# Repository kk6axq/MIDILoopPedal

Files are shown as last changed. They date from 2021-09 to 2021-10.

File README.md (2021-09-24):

# MIDI Loop Pedal
MIDILoopPedal is a Musical Instrument Digital Interface (MIDI) based loop pedal for use with an electric piano. It enables the user to record, dub, and playback multiple tracks in realtime.

This project is being conducted as an Honors Enrichment Contract for EGR201, Use-Inspired Design Project I, at Arizona State University on the Polytechnic Campus through Barrett, the Honors College, at Arizona State University, and under the guidance of Dr. Adam Carberry.
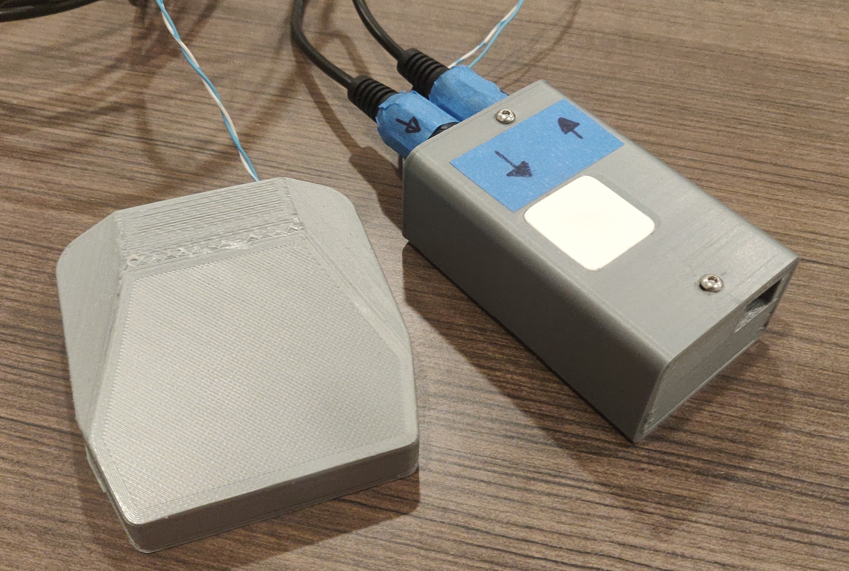
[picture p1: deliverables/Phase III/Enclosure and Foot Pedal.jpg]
Project Photo


## Project Status
This project is organized into four main phases and two stretch phases. Minimum success will be demonstrated by completion of phase IV.<br>
**Phase I: Complete**
* ~~Create block diagram of major components~~
* ~~Select electrical components and build schematic~~
* ~~Build CAD model concept~~

**Phase II: Complete**
* ~~Build breadboard layout of electrical system~~
* ~~Test functionality of electrical system to receive and send key events~~
* ~~Build Solidworks Assembly of body~~

**Phase III: Complete**
* ~~Build proto-board or PCB layout for electrical system~~
* ~~Assemble electrical and mechanical system~~

**Phase IV: In Progress**
* Develop software to record and play back key events
* Test complete system

**Stretch Goal I:**
* Add USB MIDI interface mode

**Stretch Goal II:**
* Add multi-track recording or playback

## Project Structure
This repository will contain all files from the project as it progresses. The current structure is:
* **hardware**: Hardware design files for the CAD and EDA parts of the project. CAD parts are designed in Solidworks, and the electrical schematics are designed in KiCAD.
* **software**: Source code for the testing, validation, and operation aspects of the project. The Teensy 4.1 microcontroller is programmed through the Arduino environment, and all source code is in C/C++.
* **deliverables**: Deliverables for the different phases of the project. These are copies of the different files at the time of phase completion, but they serve as a moment-in-time survey of the project and help illustrate the design evolution over time.

## Contact
To get in touch, send me an email: kk6axq@gmail.com

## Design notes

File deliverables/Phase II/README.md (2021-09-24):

# Phase II
Phase II deliverables centered around the testing of the electrical system and initial enclosure.

## Breadboard layout
The breadboard layout helped validate the schematic and component selection. The power LED was removed as the WS2812B indicator was found to be sufficient. The breadboard also allowed testing the initial software and ensuring communication between the microcontroller and the piano worked.

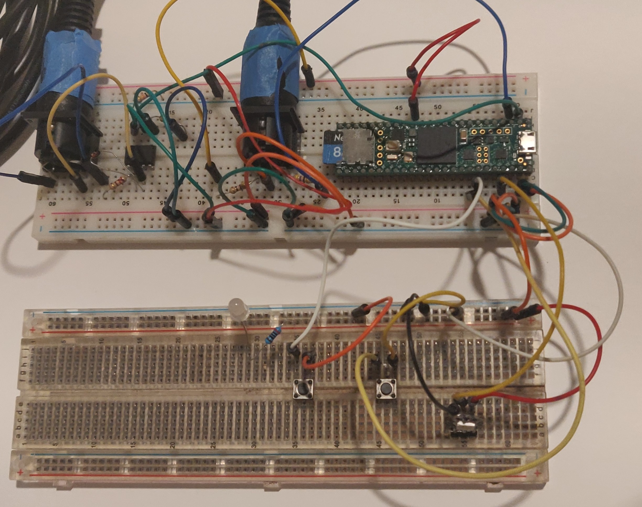
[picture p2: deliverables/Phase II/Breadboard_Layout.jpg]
PCB Front Photo


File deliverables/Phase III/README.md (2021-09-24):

# Phase III
Phase III transferred the project from a breadboard to proto board, enabling a more permanent solution. Aspects of this were completed in conjunction with Phase II, as the hardware design files for Phase II required the dimensions of the PCB from Phase III.

# Proto-board layout
The transfer from breadboard to proto-board went well. There was one minor issue with a pullup resistor that was in the wrong location (see dcd258a), but the rest of the assembly process went smoothly. Two PCBs had to be joined to create enough space for the parts, which is somewhat suboptimal, but so far it has held up well.

U2-Pin-Header was also added to the Bill of Materials as I didn't add the female pin headers that seated the microcontroller at an earlier stage.

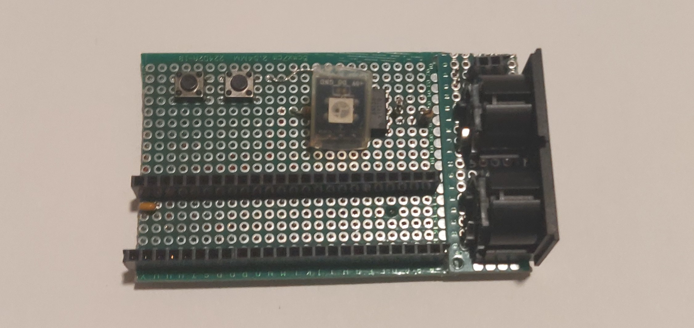
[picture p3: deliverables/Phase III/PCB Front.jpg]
PCB Front Photo

<br>
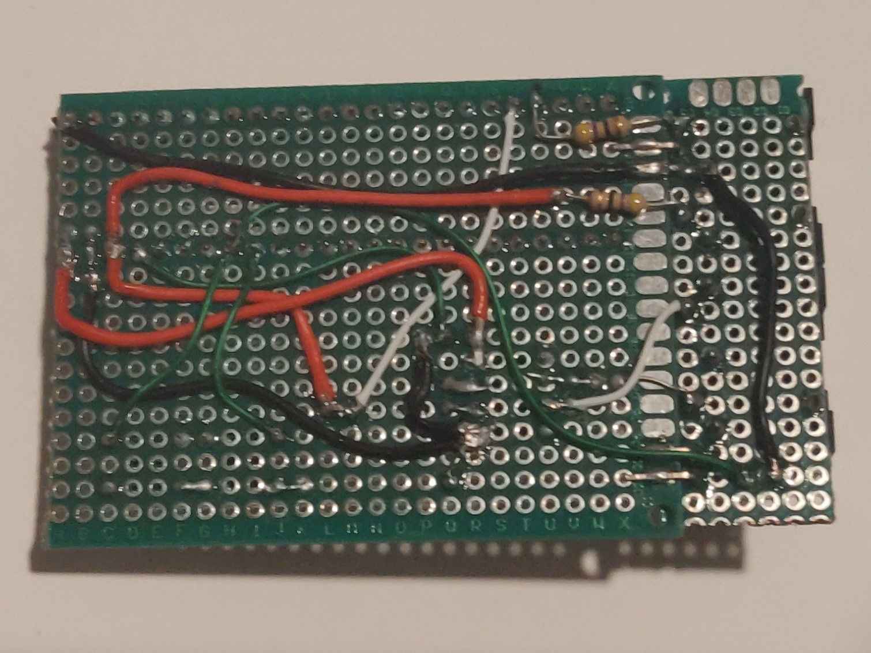
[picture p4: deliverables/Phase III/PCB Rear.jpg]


# Foot pedal
Pianists are already familiar with using foot pedals for controlling the sustain on a piano or keyboard, so I decided to use a footpedal as the control for the loop pedal. After some research, I found an open source design from Adafruit for a fully 3D printable foot pedal that interfaced with a common tactile switch. The design, available here: https://www.thingiverse.com/thing:2829107, prints in three pieces and can be easily glued or screwed together. I chose to screw the switch into the bracket and glue the bracket into the base.

# Bill of Materials
The Bill of Materials and schematic got an update as the foot pedal got added and some miscellaneous parts and connectors were included. The only two items not listed on the BOM, as far as I know, are the proto-board itself and the wire that runs between the foot pedal and the base unit. I'm currently using salvaged wire that I got at no cost, so unless I move this to commercial production, I won't add a source for the 2 conductor cable.

# Assembly
The order of assembly is fairly straightforward:
* Assemble the PCB
* Glue the connector bracket to the connectors. For this I used hot glue for ease of removability if ever needed.
* Insert the captive nuts into the slots on the connector bracket and USB end cap.
* Fit and glue the window into the slot in the enclosure tube.
* Slide the PCB into the enclosure tube, with the connectors at the slightly closed end.
* Install the USB end cap to hold the PCB in place.
* Install the 2 M3x12 screws to hold the connector bracket and USB end cap in place.
Board Photo

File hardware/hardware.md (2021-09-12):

The KiCAD project depends on symbols and footprints from the Teensy KiCAD library, included as a submodule in the `libraries` folder: https://github.com/XenGi/teensy_library

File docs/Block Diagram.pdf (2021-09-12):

Microcontroller
(Teensy 4.1)

MIDI
Interface
Circuitry
Computer | Instrument

LED
Indicator

Buttons

Storage Medium
Built-In

Red: Power (3.3/5V)
Blue: UART
Green: GPIO
Orange: MIDI

Internal to device

MIDI Loop Pedal Component Block Diagram

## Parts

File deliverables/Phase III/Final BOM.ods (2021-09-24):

MIDI Loop Pedal |  |  |  |  | Revision | 2
Bill of Materials
Electrical parts
Designator | Value | Qty | Unit Price | Qty 10 Price | Digikey Part # | Note |  | Single unit price | Batch price
SW1, SW2 | Tactile SPST | 2 | $0.10 | $0.091 | 679-2428-ND
SW3 | Micro-switch | 1 | $1.95 | $1.760 | https://www.adafruit.com/product/817 | Standard arcade button
U1 | 6N138 | 1 | $0.80 | $0.522 | 160-1795-ND |  |  | $0.80 | $0.522
U2 | Teensy 4.1 | 1 | $31.88 | $31.880 | 1568-DEV-16996-ND | Cheaper without headers |  | $31.88 | $31.880
C1 | 0.1u | 1 | $0.23 | $0.157 | 399-4151-ND |  |  | $0.23 | $0.157
R1,R3 | 470 | 2 | $0.10 | $0.036 | CF14JT470RCT-ND |  |  | $0.20 | $0.072
R2 | 10k | 1 | $0.10 | $0.036 | CF14JT10K0CT-ND |  |  | $0.10 | $0.036
R4,R5 | 47 | 2 | $0.10 | $0.036 | CF14JT47R0CT-ND |  |  | $0.20 | $0.072
D1 | 1N4148 | 1 | $0.10 | $0.071 | 1N4148-T26ACT-ND |  |  | $0.10 | $0.071
D3 | WS2812B | 1 | $0.10 | $0.103 | N/A | One module from a generic WS2812B strip. |  | $0.10 | $0.103
J1,J2 | DIN-5 | 2 | $2.15 | $1.870 | CP-2350-ND |  |  | $4.30 | $3.740
J3 | 2 pin female | 1 | $0.10 | $0.076 | 2057-PH1RA-02-UA-ND |  |  | $0.10 | $0.076
J4 | 2 pin male | 1 | $0.18 | $0.149 | 2057-RS1-02-G-ND |  |  | $0.18 | $0.149
U2-Pin-Header | 24 pin | 2 | $1.37 | $1.193 | S7022-ND | Female headers for making U2 removable |  | $2.74 | $2.386
 |  |  |  |  |  |  | Single unit part cost | $40.93
 |  |  |  |  |  |  | Batch of 10 units part cost |  | $39.26
Mechanical parts |  |  |  |  | Note:
Name | Qty | Unit Price | Note |  | All 3D printed part costs estimated by slicer weight with supports at $25/kg
M3x12 bolt | 4 | $0.02
M3 nut | 4 | $0.02
Connector Bracket | 1 | $0.05
USB End Cap | 1 | $0.15
Enclosure Tube | 1 | $1.10
Window | 1 | $0.03 | White or clear filament
Pedal Top | 1 | $0.58
Pedal Bracket | 1 | $0.08
Pedal Base | 1 | $0.48
 | Part cost: | $2.49
Total cost: | Electrical | Mechanical | Net Cost | Unit Cost
1 unit | $40.93 | $2.49 | $43.42 | $43.42
10 units | $392.64 | $24.90 | $417.54 | $41.75

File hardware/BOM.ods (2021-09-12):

MIDI Loop Pedal |  |  |  |  | Revision | 2
Bill of Materials
Designator | Value | Qty | Unit Price | Qty 10 Price | Digikey Part # | Note |  | Single unit price | Batch price
U1 | 6N138 | 1 | $0.80 | $0.522 | 160-1795-ND |  |  | $0.80 | $0.522
U2 | Teensy 4.1 | 1 | $31.88 | $31.880 | 1568-DEV-16996-ND | Cheaper without headers |  | $31.88 | $31.880
C1 | 0.1u | 1 | $0.23 | $0.157 | 399-4151-ND |  |  | $0.23 | $0.157
R1,R3 | 470 | 2 | $0.10 | $0.036 | CF14JT470RCT-ND |  |  | $0.20 | $0.072
R2 | 10k | 1 | $0.10 | $0.036 | CF14JT10K0CT-ND |  |  | $0.10 | $0.036
R4,R5 | 47 | 2 | $0.10 | $0.036 | CF14JT47R0CT-ND |  |  | $0.20 | $0.072
R6 | 220 | 1 | $0.10 | $0.036 | CF14JT220RCT-ND |  |  | $0.10 | $0.036
D1 | 1N4148 | 1 | $0.10 | $0.071 | 1N4148-T26ACT-ND |  |  | $0.10 | $0.071
D2 | Red | 1 | $0.15 | $0.140 | C503B-RCN-CW0Z0AA1-ND |  |  | $0.15 | $0.140
D3 | WS2812B | 1 | $0.10 | $0.103 | N/A | One module from a generic WS2812B strip. |  | $0.10 | $0.103
J1,J2 | DIN-5 | 2 | $2.15 | $1.870 | CP-2350-ND |  |  | $4.30 | $3.740
J3 | 2 pin | 1 | $0.10 | $0.076 | 2057-PH1RA-02-UA-ND |  |  | $0.10 | $0.076
 |  |  |  |  |  |  | Single unit part cost | $38.26
 |  |  |  |  |  |  | Batch of 10 units part cost |  | $36.90

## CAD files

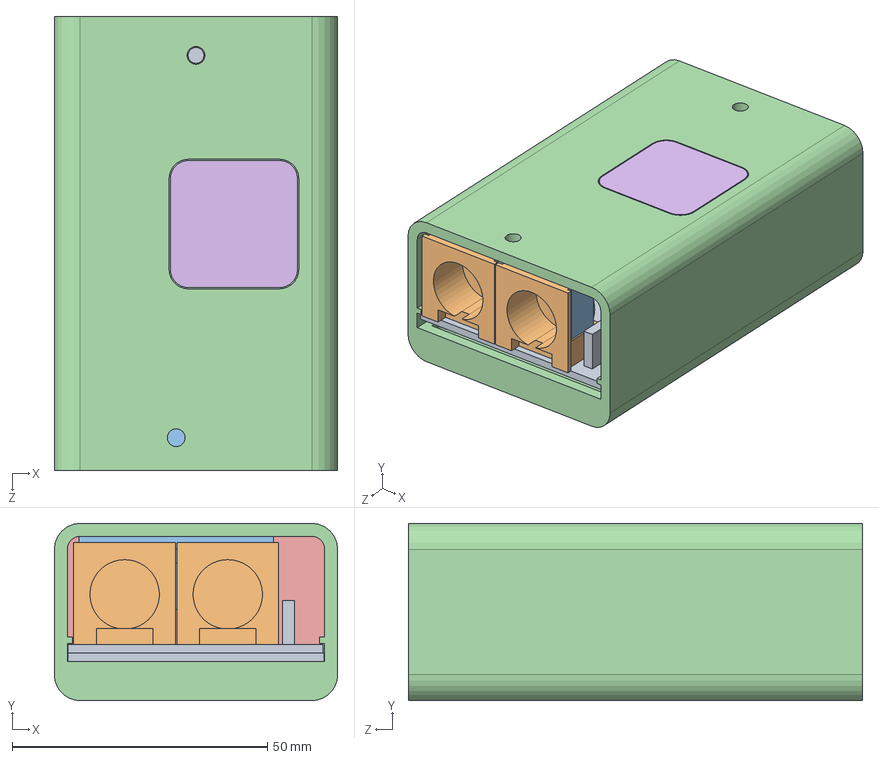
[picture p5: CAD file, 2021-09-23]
deliverables/Phase II/Enclosure Solidworks Files/V1 Assembly.SLDASM
55.5 x 34.7 x 88.9 mm
Proto-board
MIDI-connector x 2
Connector-Bracket
Enclosure-Tube
USB-End-Cap-v1
Window

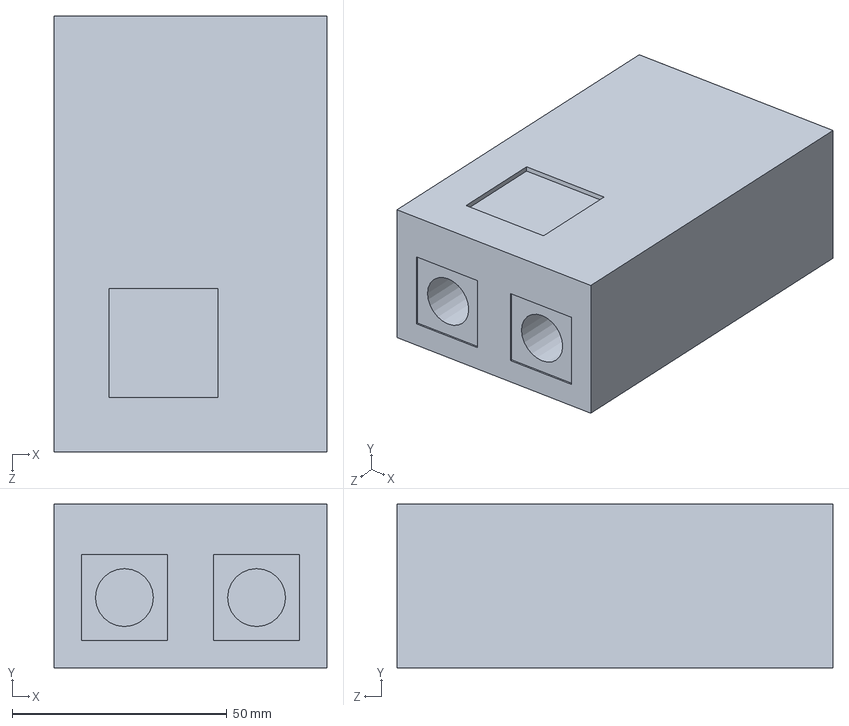
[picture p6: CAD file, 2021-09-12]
deliverables/Phase I/Device Mockup.SLDPRT
63.5 x 38.1 x 101.6 mm

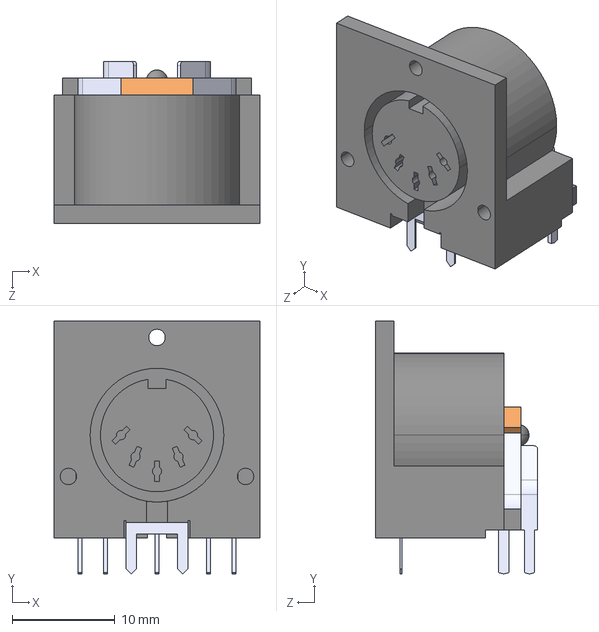
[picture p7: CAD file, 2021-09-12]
hardware/CAD/external_parts/MIDI_Connector.STEP
20.0 x 24.6 x 15.8 mm

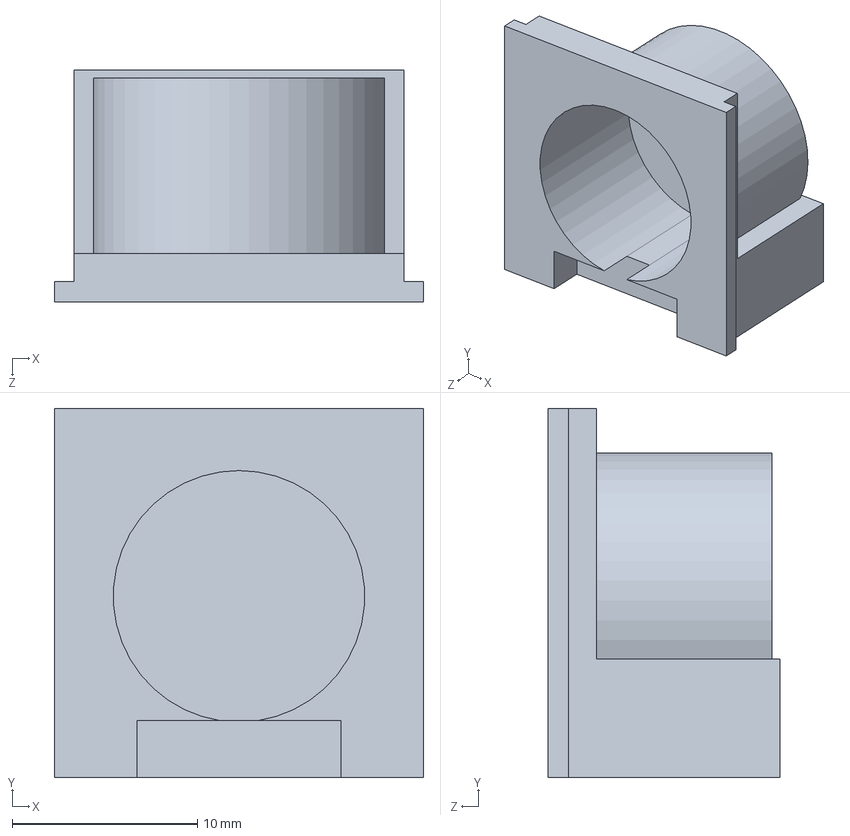
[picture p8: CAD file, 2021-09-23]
deliverables/Phase II/Enclosure Solidworks Files/MIDI-connector.SLDPRT
19.9 x 19.9 x 12.5 mm

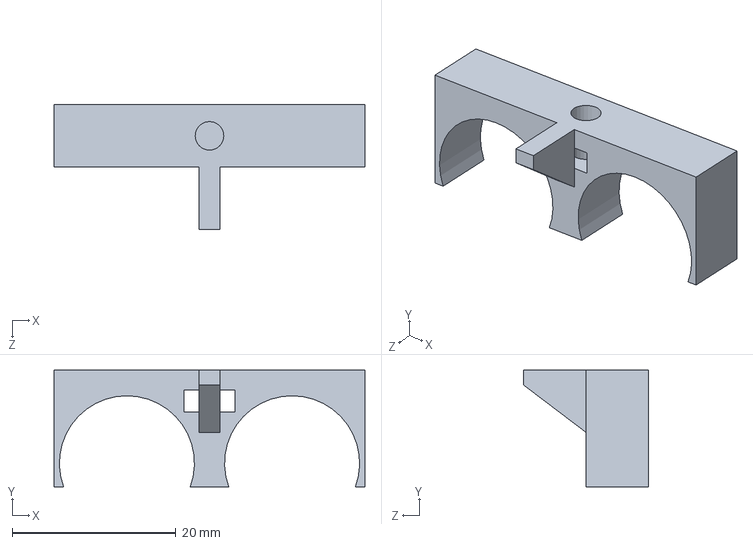
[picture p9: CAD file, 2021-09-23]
deliverables/Phase II/Enclosure Solidworks Files/Connector-Bracket.SLDPRT
38.0 x 14.3 x 15.2 mm

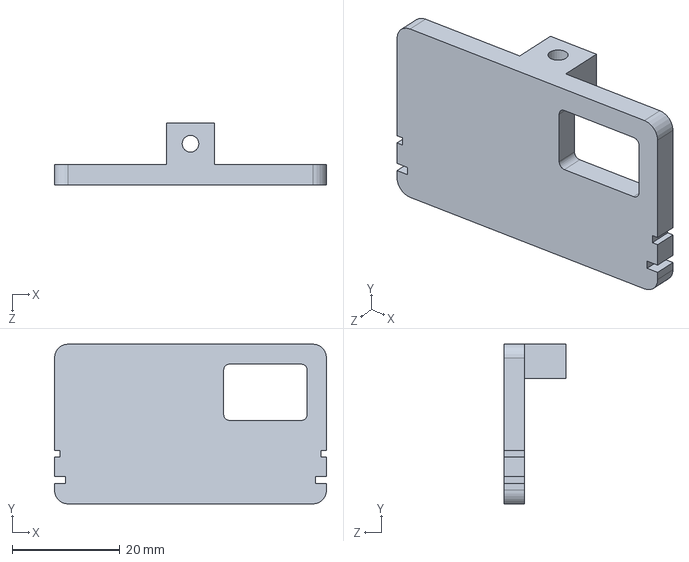
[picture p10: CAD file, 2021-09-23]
deliverables/Phase II/Enclosure Solidworks Files/USB-End-Cap-v1.SLDPRT
50.4 x 29.6 x 11.4 mm

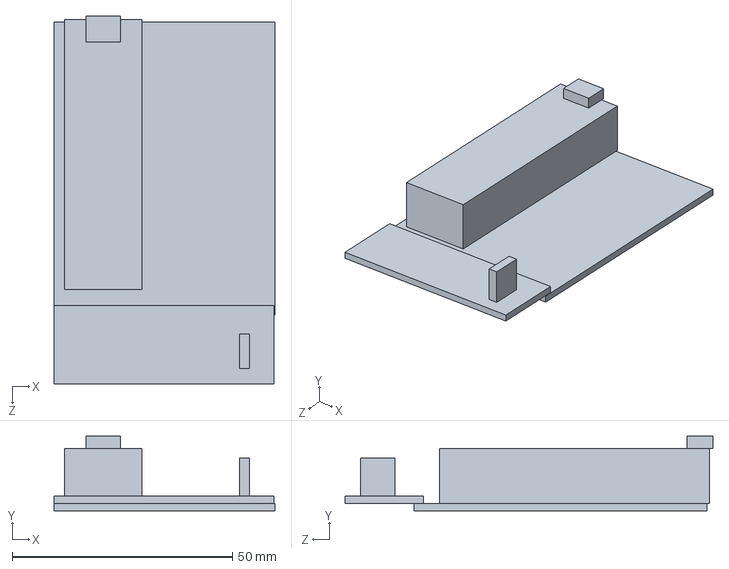
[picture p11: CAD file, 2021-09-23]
deliverables/Phase II/Enclosure Solidworks Files/Proto-board.SLDPRT
50.2 x 17.0 x 83.5 mm

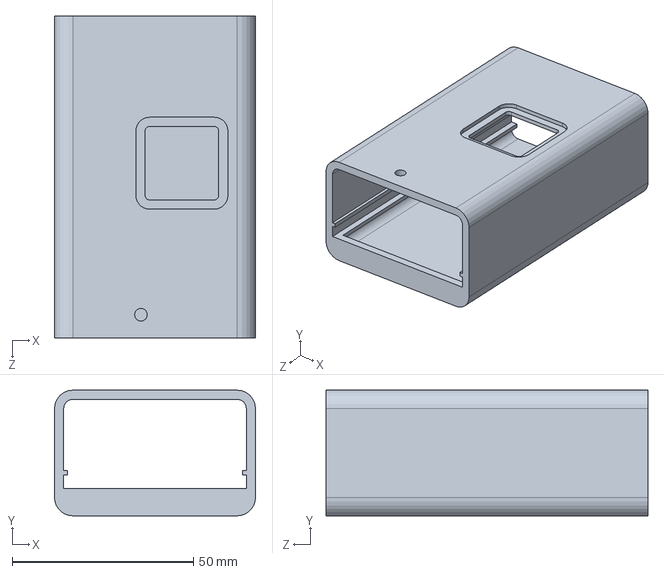
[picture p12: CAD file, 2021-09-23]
deliverables/Phase II/Enclosure Solidworks Files/Enclosure-Tube.SLDPRT
55.5 x 34.7 x 88.9 mm

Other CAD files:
deliverables/Phase II/Enclosure Solidworks Files/Window.SLDPRT
deliverables/Phase II/Enclosure STLs/Connector-Bracket.STL
deliverables/Phase II/Enclosure STLs/Enclosure-Tube.STL
deliverables/Phase II/Enclosure STLs/USB-End-Cap-v1.STL
deliverables/Phase II/Enclosure STLs/Window.STL

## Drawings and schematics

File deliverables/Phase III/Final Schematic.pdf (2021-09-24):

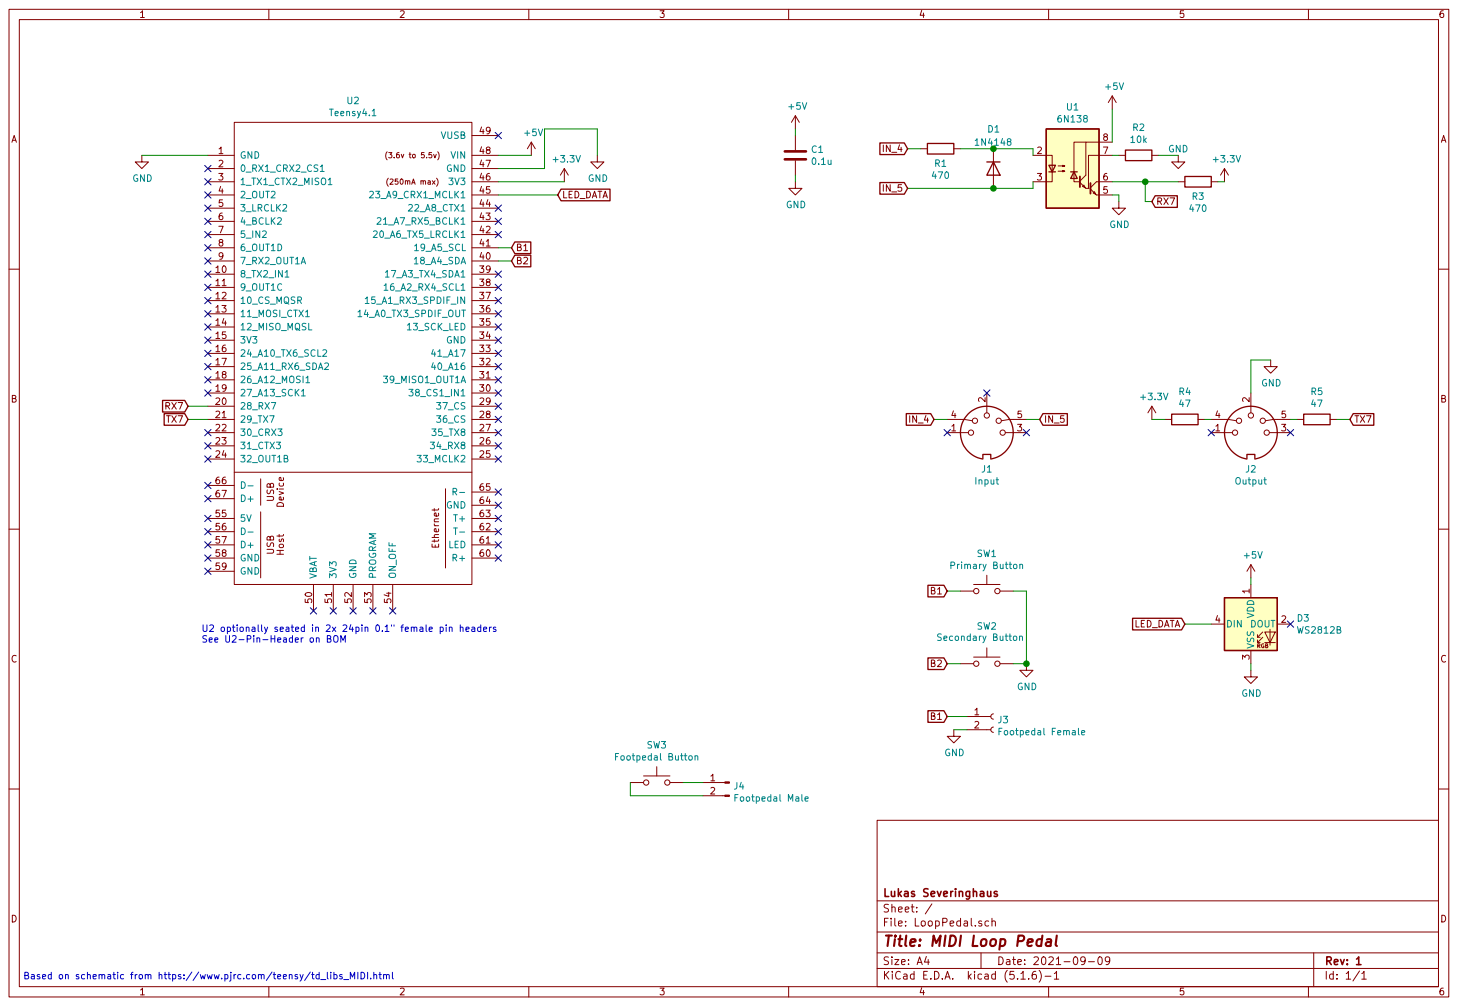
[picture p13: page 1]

LED_DATA RX7 Based on schematic from https://www.pjrc.com/teensy/td_libs_MIDI.html

U2 optionally seated in 2x 24pin 0.1" female pin headers See U2-Pin-Header on BOM

File: LoopPedal.sch Sheet: / Lukas Severinghaus

Id: 1/1 Title: MIDI Loop Pedal

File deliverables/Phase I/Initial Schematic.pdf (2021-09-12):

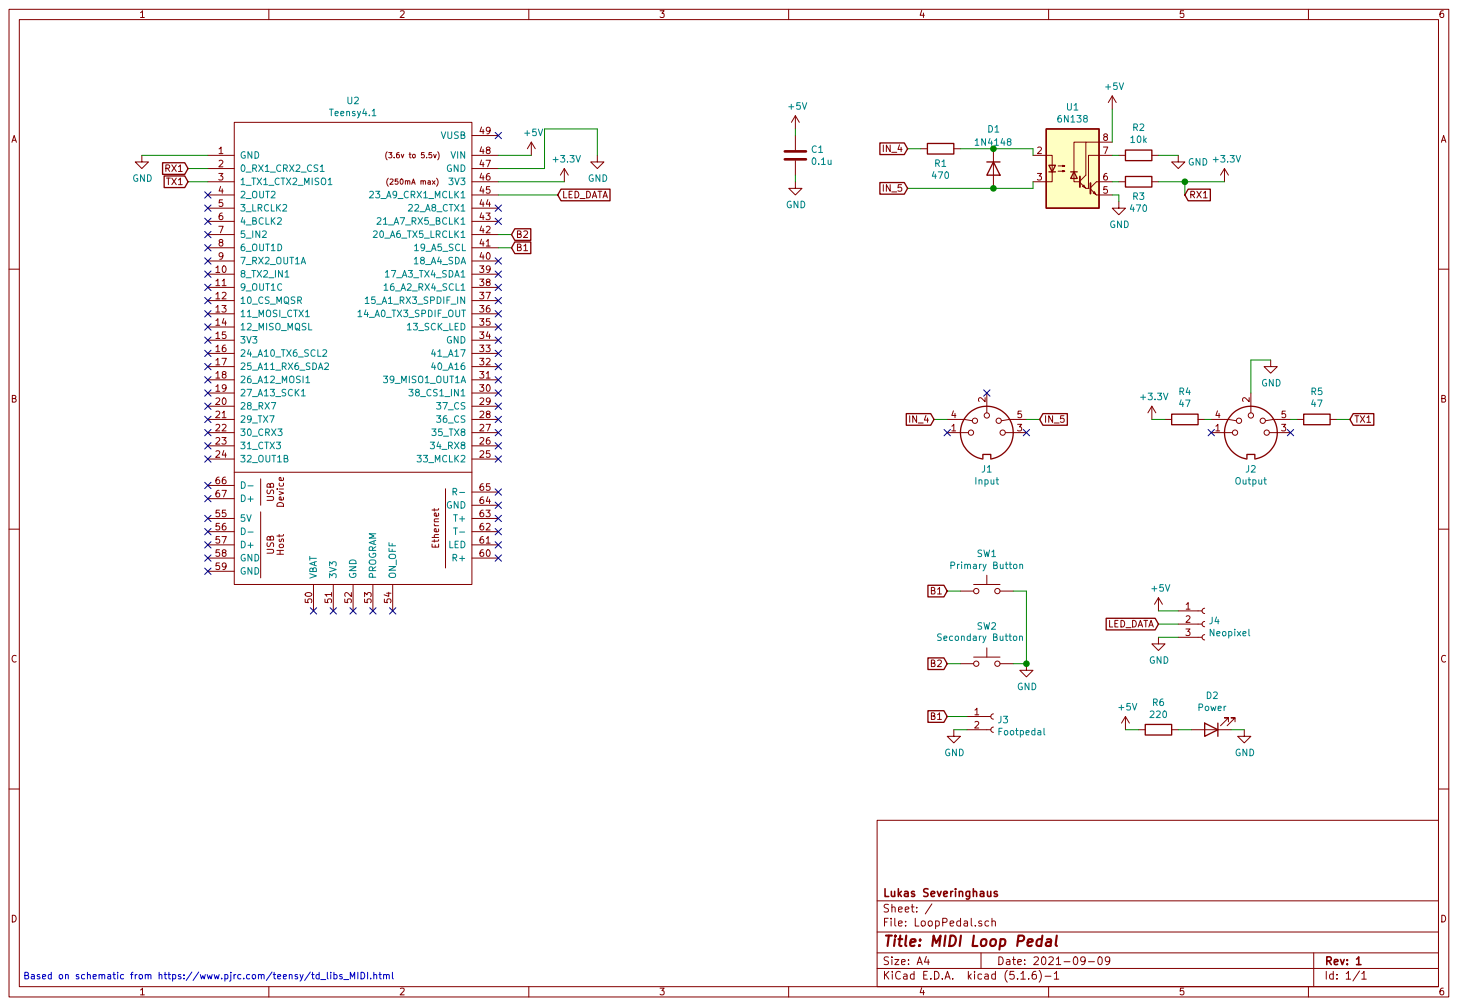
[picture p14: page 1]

Id: 1/1 Title: MIDI Loop Pedal

Based on schematic from https://www.pjrc.com/teensy/td_libs_MIDI.html

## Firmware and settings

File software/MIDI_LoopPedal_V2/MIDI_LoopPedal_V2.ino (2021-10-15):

/**
 * Loop Pedal V2
 * Lukas Severinghaus
 * October 15, 2021
 * 
 * Remake of loop pedal code.
 * 
 * Still TODO:
 * * Normalize function names either underscores or camelcase.
 */

#include <MIDI.h>
#include <Bounce.h>
// Configuration
MIDI_CREATE_INSTANCE(HardwareSerial, Serial7, MIDI);
#define RECORD_PIN 19
#define RESET_PIN 18
#define LED_PIN 23

// State machine states
#define STATE_RESET 0
#define STATE_WAITING 1
#define STATE_RECORD 2
#define STATE_PLAYBACK 3
#define STATE_DUBBING 4 //Simultaneous playback and recording

byte state_machine_state = STATE_WAITING;
bool state_transition = true;

bool reset_flag = false;
bool record_flag = false;

// MIDI packet types
#define TYPE_NOTE_ON 0x90
#define TYPE_NOTE_OFF 0x80
#define TYPE_CONTROL_MODE 0xB0 
#define TYPE_INVALID 0x00
// Button handlers
Bounce record_button = Bounce(RECORD_PIN, 20);
Bounce reset_button = Bounce(RESET_PIN, 20);

/**** MIDI Data ****/
typedef struct{
  int time;
  byte type;
  int d1; //Note
  int d2; //Velocity
  int channel;
} MIDI_Event;

MIDI_Event incoming_MIDI_event;
bool has_new_MIDI_event = false;

#include <FastLED.h>
CRGB led[1];

void setup() {
  initializeHardware();
}

void loop() {
  pollHardware(); // Check buttons and USB MIDI buffer

  
  
  switch(state_machine_state){
    case STATE_WAITING:
      state_waiting();
    break;

    case STATE_RECORD:
      state_record();
    break;

    case STATE_PLAYBACK:
      state_playback();
    break;

    case STATE_DUBBING:
      state_dubbing();
    break;
    
    case STATE_RESET:
      handleReset();
    break;
  }
}


/**** State Machine and Process Code ****/

void state_waiting(){
  if(state_transition){
    setLEDColor(250, 250, 250);
    Serial.println("Entering waiting state");
    state_transition = false;
  }
  if(record_flag){
    Serial.println("Record pressed, transitioning state");
    record_flag = false;
    incrementState();
  }
}

// Is this the first time recording?
bool record_first_record = true;
long record_start_time = 0;
long record_stop_time = 0;

long track_duration = 0;
void state_record(){
  if(state_transition){
    state_transition = false;
    setLEDColor(255, 0, 0);
    Serial.println("Start recording");
    if(record_first_record){
      record_start_time = millis();
    }
  }

  if(record_first_record && record_flag){
    record_first_record = false;
    record_flag = false;
    
    record_stop_time = millis();
    track_duration = record_stop_time - record_start_time;
    
    Serial.println(String("Done recording first time, track length is ") + track_duration + " ms");
    incrementState();
  }
}

long playback_start_time = 0;
void state_playback(){
  if(state_transition){
    state_transition = false;
    setLEDColor(0, 255, 0);
    playback_start_time = millis();
    Serial.println("Start playback");
  }
  
  play_event(millis() - playback_start_time);
  
  if(millis() > playback_start_time + track_duration){
    Serial.println("Done with playback, transitioning");
    incrementState();
  }
}

long dubbing_start_time = 0;
void state_dubbing(){
  if(state_transition){
    state_transition = false;
    setLEDColor(0, 0, 255);
    dubbing_start_time = millis();
    Serial.println("Start dubbing");
    incrementDubbingTrack();
  }

  if(has_new_MIDI_event){
    record_event(millis() - dubbing_start_time);
  }
  play_event(millis() - playback_start_time);
  
  if(millis() > dubbing_start_time + track_duration){
    Serial.println("Done with dubbing, transitioning");
    incrementState();
  }
}
/**
 * Called when the reset button is pressed, stops current playback and resets the system to defaults.
 */
void handleReset(){
  Serial.println("Reset triggered.");
  state_machine_state = STATE_WAITING;
  state_transition = true;
  //Set recording to record from new again
  record_first_record = true;
}

/**
 * Increments the state machine to the next state, depending on the current state.
 */
void incrementState(){
  //Serial.print("Was in state: ");
  //Serial.print(state_machine_state);
  switch(state_machine_state){
    case STATE_WAITING:
      state_machine_state = STATE_RECORD;
      break;
    case STATE_RECORD:
      state_machine_state = STATE_PLAYBACK;
      break;
    case STATE_PLAYBACK:
      if(reset_flag){
        state_machine_state = STATE_RESET;
        reset_flag = false;
      }else if(record_flag){
        state_machine_state = STATE_DUBBING;
        record_flag = false;
      }
      break;
    case STATE_DUBBING:
      state_machine_state = STATE_PLAYBACK;
      break;
    default:
      state_machine_state = STATE_RESET;
      break;
  }
  state_transition = true;
  //Serial.print(" now in state: ");
  //Serial.println(state_machine_state);
}

/**** End State Machine and Process Code ****/

/**** Hardware Interface Code ****/

/**
 * Sets up hardware peripherals
 */
void initializeHardware(){
  pinMode(RECORD_PIN, INPUT_PULLUP);
  pinMode(RESET_PIN, INPUT_PULLUP);
  Serial.begin(115200);
  MIDI.begin(MIDI_CHANNEL_OMNI);
  usbMIDI.begin();
  FastLED.addLeds<1, WS2812B, LED_PIN, GRB>(led, 1);
  FastLED.setBrightness(40);
}

/**
 * Checks button states and sets the appropriate flag
 */
void pollHardware(){
  //Serial.println("Polling hardware");
  //Don't clear the flags, only set them, in case
  //the system can't get to them before the button changes again.
  if(record_button.update()){
    if(record_button.fallingEdge()) record_flag = true; //Serial.println("Record pressed");
  }
  if(reset_button.update()){
    if(reset_button.fallingEdge()) reset_flag = true; //Serial.println("Reset pressed");
  }

  //Check USB MIDI buffer and send any messages that have arrived.
  readUSBMIDI();
  readMIDIHardware();
}

/**
 * Checks for packet in the USB MIDI buffer, immediately sends it if one is present.
 */
void readUSBMIDI(){
  byte type, d1, d2, channel;
  if(usbMIDI.read()){
    type = usbMIDI.getType();
    d1 = usbMIDI.getData1();
    d2 = usbMIDI.getData2();
    channel = usbMIDI.getChannel();
    MIDI.send(type, d1, d2, channel);
    Serial.println(String("Got packet from USB: ") + type + ", " + d1 + ", " + d2 + ", " + channel);
  }
}

/**
 * Checks for incoming MIDI messages from the hardware interface, only allows processing note on, note off, and control mode messages.
 * Sends them over USB and saves the most recent message for processing.
 */
void readMIDIHardware(){
  byte type, d1, d2, channel;
  if(MIDI.read()){
    type = MIDI.getType();
    d1 = MIDI.getData1();
    d2 = MIDI.getData2();
    channel = MIDI.getChannel();
    if (type == TYPE_NOTE_ON || type == TYPE_NOTE_OFF || type == TYPE_CONTROL_MODE){
      Serial.println(String("Got packet from device: ") + type + ", " + d1 + ", " + d2 + ", " + channel);
      //This is a packet that needs to be processed.
      //Send it to the computer.
      sendToComputer(type, d1, d2, channel);

      //Save for processing and set the new message flag.
      incoming_MIDI_event.type = type;
      incoming_MIDI_event.d1 = d1;
      incoming_MIDI_event.d2 = d2;
      incoming_MIDI_event.channel = channel;

      has_new_MIDI_event = true;
    }
  }
}

/**
 * Sends a packet to the computer if it's one of the three valid types.
 */
void sendToComputer(byte type, byte d1, byte d2, byte channel){
  if(type == TYPE_NOTE_ON){
    usbMIDI.sendNoteOn(d1, d2, channel);
  }else if(type == TYPE_NOTE_OFF){
    usbMIDI.sendNoteOff(d1, d2, channel);
  }else if(type == TYPE_CONTROL_MODE){
    usbMIDI.sendControlChange(d1, d2, channel);
  }
}

void setLEDColor(byte r, byte g, byte b){
  led[0] = CRGB(r, g, b);
  FastLED.show();
}
/**** End Hardware Interface Code ****/

/**** Recording and Playback Code ****/

#define MAX_MIDI_TRACKS 10
#define MAX_MIDI_EVENTS 1500
int currentTrack = 0;
int currentTrackIndex = 0;
MIDI_Event recorded_events[MAX_MIDI_TRACKS][MAX_MIDI_EVENTS];
void incrementDubbingTrack(){
  currentTrackIndex = 0;
  if(currentTrack == MAX_MIDI_TRACKS-1){
    Serial.println("No more tracks to record on. Going back to playback");
    incrementState();
  }else{
    currentTrack += 1;
    Serial.println(String("Now recording on track ") + currentTrack); 
  }
}

void play_event(long relative_time){
  
}

void record_event(long relative_time){
  incoming_MIDI_event.time = relative_time;
  recorded_events[currentTrack][currentTrackIndex] = incoming_MIDI_event;
  currentTrackIndex += 1;
}

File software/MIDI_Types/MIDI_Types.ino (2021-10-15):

/**
 * MIDI Message Analysis
 * Lukas Severinghaus
 * September 27, 2021
 * 
 * Listens for MIDI messages and logs the types of messages received.
 * Use this to detect what messages the piano sends for different inputs.
 */

#include <MIDI.h>
MIDI_CREATE_INSTANCE(HardwareSerial, Serial7, MIDI);

void setup() {
  MIDI.begin(MIDI_CHANNEL_OMNI);
  Serial.begin(115200);
}
byte received_types[50];
int current_index = 0;
void loop() {
  if(MIDI.read()){
    byte type = MIDI.getType();
    bool in_array = false;
    for(int i = 0; i < current_index; i++){
      if(received_types[i] == type){
        in_array = true;
      }
    }
    if(!in_array){
      received_types[current_index] = type;
      current_index += 1;
    }
  }

  if(millis() % 100 == 0){
    for(int i = 0; i < current_index; i++){
      Serial.print(int(received_types[i]));
      Serial.print(", ");
    }
    Serial.println();
  }
}

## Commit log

2021-09-12 Add Phase I deliverables and hardware files
    [BOM.ods, Device Mockup.SLDPRT, Initial BOM.ods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]
2021-09-12 Update submodule for Teensy footprint and update KiCAD files.
2021-09-15 Fix schematic issue
    Also had to restore backup schematic file as it didn't appear to save correctly last time.
    [LoopPedal.sch]
2021-09-15 Update pin mapping to reflect proto-board layout
    MIDI was moved from Serial1 to Serial 7.
    Button 2 was moved from pin 20 to pin 18.
    [LoopPedal.sch]
2021-09-23 Add Enclosure V1 CAD files
    [Connector-Bracket.SLDPRT, Connector-Bracket.STL, Enclosure-Tube.SLDPRT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]
2021-09-23 Add Phase II CAD deliverables
    [Connector-Bracket.SLDPRT, Connector-Bracket.STL, Enclosure-Tube.SLDPRT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]
2021-09-24 Update schematic and BOM. Add Phase III deliverables
    [Final BOM.ods, LoopPedal.sch]
